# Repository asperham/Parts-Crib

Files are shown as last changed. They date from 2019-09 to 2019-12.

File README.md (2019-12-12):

# Parts-Crib/Luminosity Sensor Build Instructions

# Introduction 
This project utilizes the STM32, a V2 link, blue pill and the VCNL 4010 proximity sensor. The STM32 is an Arduino alternative that uses the Arduino IDE and has similar functions. For this project we will be using the I2C pins on the STM32 in order to get readings from the VCNL 4010. The V2 link simply allows us to use the STM32 with the Arduino IDE and the VCNL 4010 is a proximity and ambient sensor. The purpose of this project is to turn on another device when the user puts their phone close to the proximity sensor. To emulate this, we will simply use an LED on one of the output pins on the STM32 to ensure that we assembled it properly. 

The following is a schematic of the breadboard:
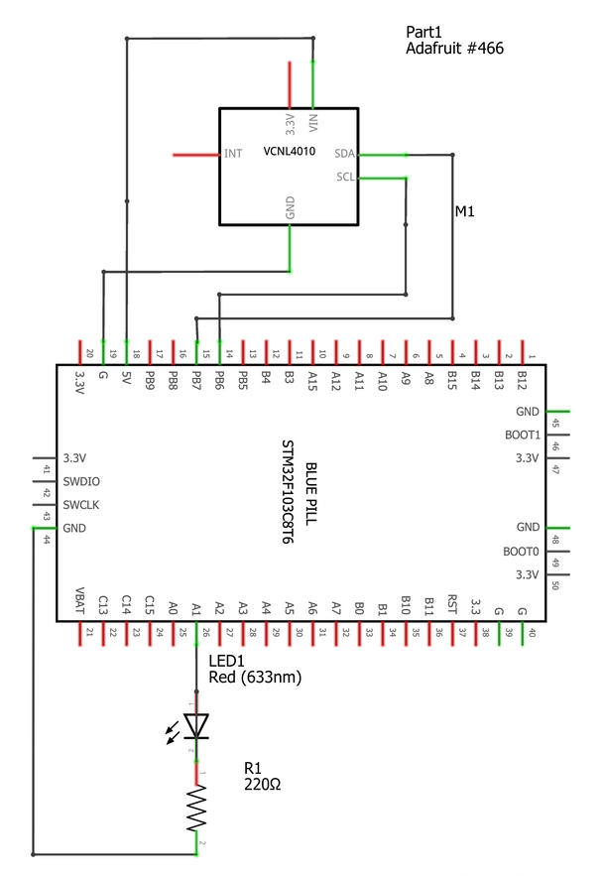
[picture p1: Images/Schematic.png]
Image of BreadBoard


The VCNL 4010 has a SCL and a SDA pins which we will connect to the I2C pin on the 4010 which are B6 and B7 respectively. The we can connect an LED to one of the output pins on the STM32 such as A1. The connections and setup will be covered on further detail in the Mechanocal Assembly section of this manuel.  

# Materials Required
The materials requred for this project are the STM32, a V2 link, the VCNL 4010, an LED, a resisor, PCB, M3 machine screws, and materials for 3D printing. You can refer to the following budget for materials: 

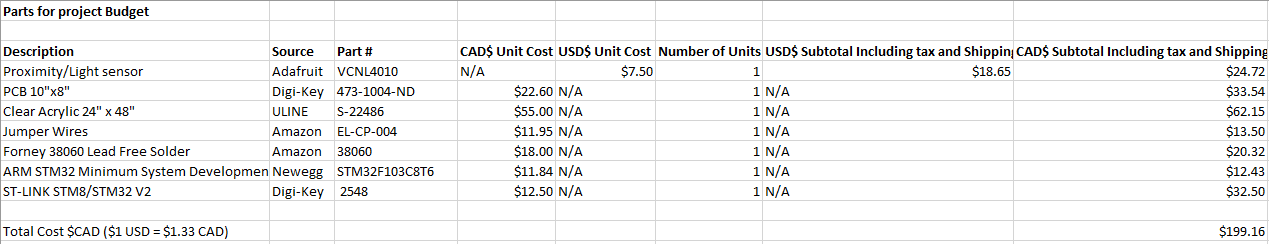
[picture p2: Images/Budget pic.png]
Image of Budget


# Time Commitment
This project can relaistically be compleated in a couple of weeks as it does not require a lot of waiting. The only things that will take the most time will be waiting for the parts, creating the PCB, and soldering. However, you can refer to the following time scedule: 

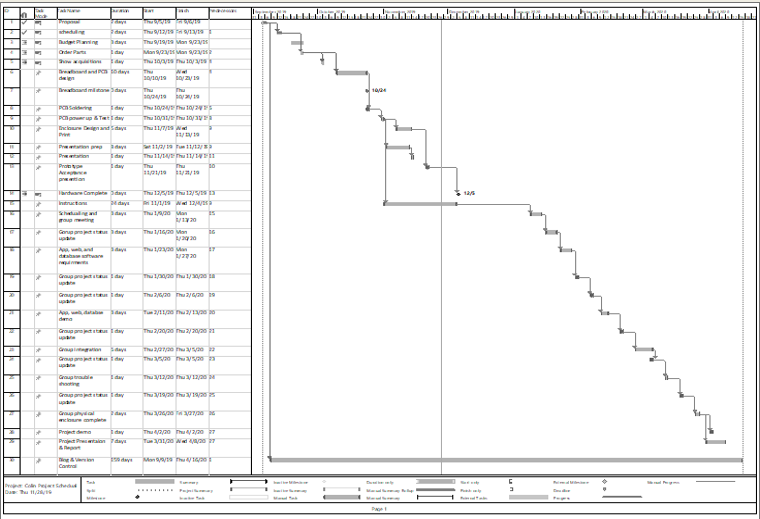
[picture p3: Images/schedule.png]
Image of schedule


# Mechanical Assembly
For the mechanical assembly we first need to test and create the breadboard. You can use the following design for the breadboard: 
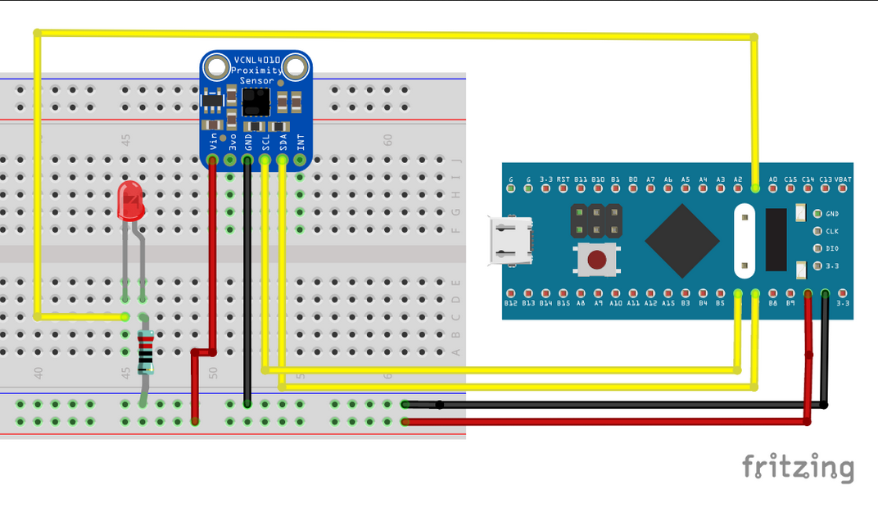
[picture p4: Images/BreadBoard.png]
Image of breadboard

Ensure that you have to proper pins connected. From here you can connect the V2 link into your computer by connecting the correspoding pins to the STM32. From here you can load the following code onto the STM32:

Link to code

From here you can you can put your hand infront of the VCNL4010 and the LED should turn on. If it does not, make sure that you initialize the I2C pins by importing the Wire.h header file and putting Wire.begin(); at the beginning of the code. 

From here we can now create the case for out PCB which will be made in the next step. The case will look like the following: 

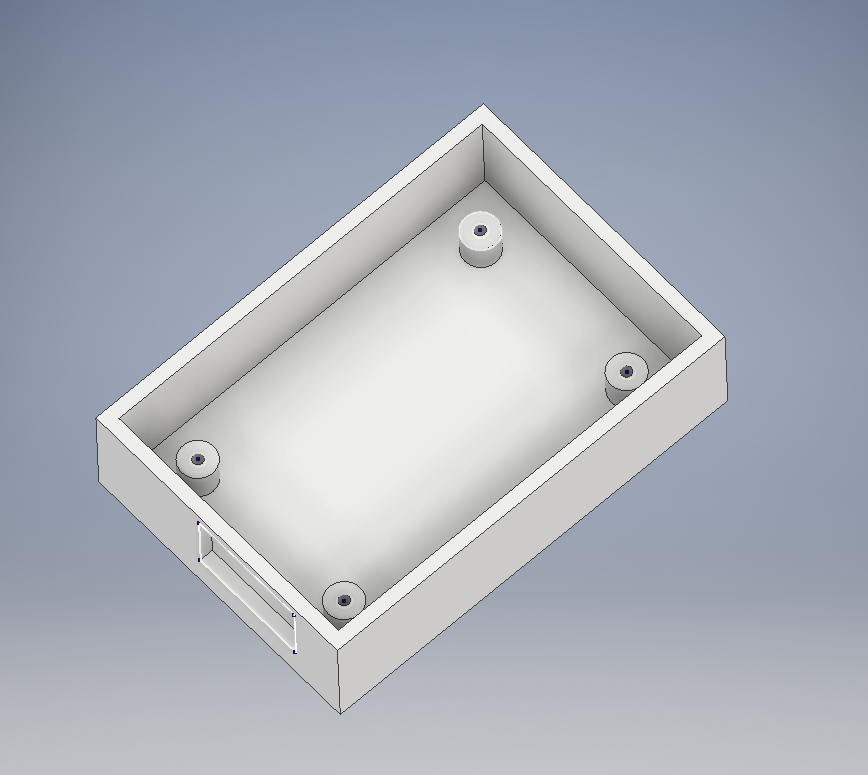
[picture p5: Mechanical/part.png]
image of case

The files for the case can be found here: Link to case files

The file is an STL file which needs to be sliced in software such as Cure before we can 3d print it. Once we slice it make sure that you add supports and fill the wall by about 50%. After this we can proceed to print the case. After it has completed and the breadboard works, we can move onto the next step.

# PCB / Soldering
For the PCB, we need to ensure that all pins are connected properly, For the PCB we can use headers, but they are not necessary for mass production. The PCB we will be creating will look like the following:
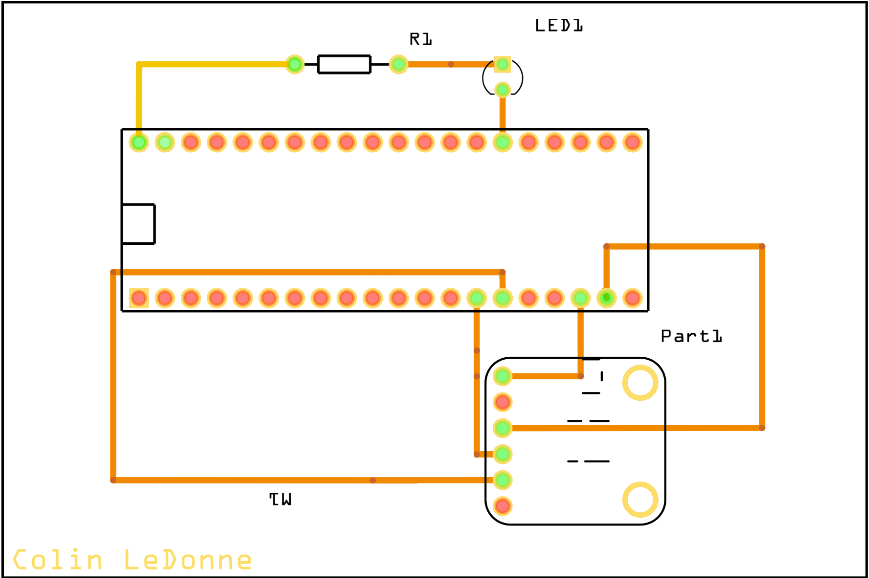
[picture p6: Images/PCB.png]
Image of PCB


For this to be created we need the gerber files which can be found From this link

Once we have the PCB created we can now solder the parts to the PCB. Ensure that you are properly safty trained before using a soldering iron. we are only going to solder the pins we need to be attached to the PCB however, you can still solder all of the pins to the PCB if you wish. Once compleated, the PCB should look somthing like the following:

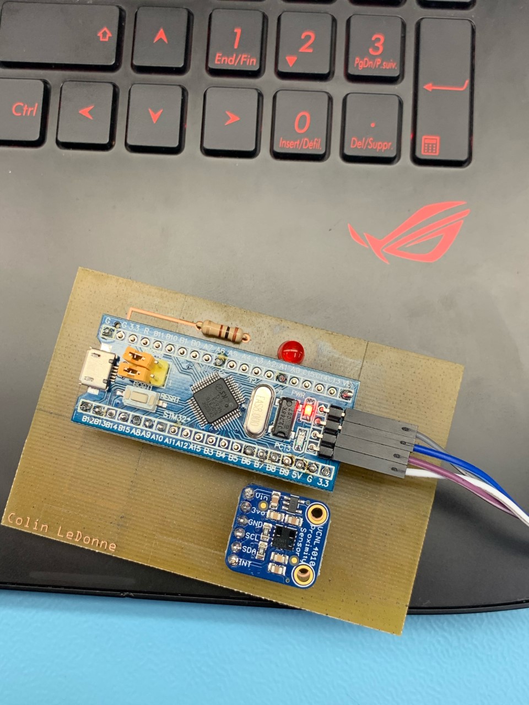
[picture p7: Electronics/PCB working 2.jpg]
image if PCB


Once all parts are soldered we can now trim the pins on the bottom of the PCB so we can put in into the case, but before we do this, we need to make sure that the PCB works properly.

# Power Up
Before you power up the PCB connect it to a multimeter with it connected to the power and ground. Ensure that you do not get any reading. If you get a reading, it means that you created a short. Check the soldering and make sure you did not create any uninteded connections. If you did, you can simply use a solder sucker to fix it. If you do not get a reading, we can now power it up. After poweing it up we can test that the PCB still works by putting out hand infront of the proximity sensor and it should look like the following: 

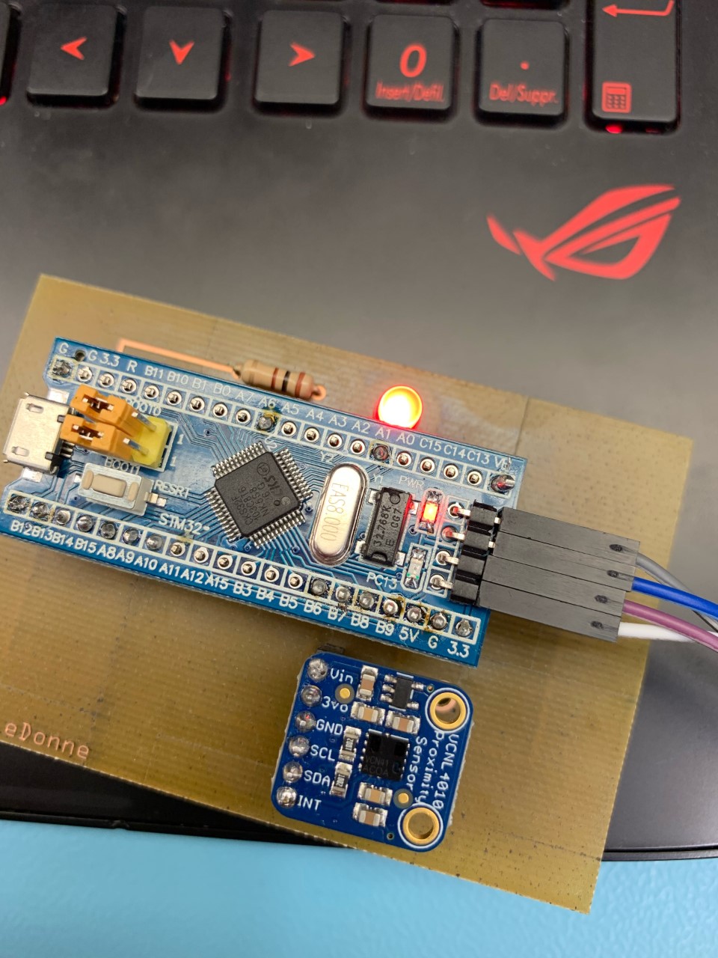
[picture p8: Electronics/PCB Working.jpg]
image of PCB on


From here we can now connect the PCB to the case we made earlier. To do this we need to make four holes on the corners of the PCB 7mm from each edge. Use a M3 machine screw drill bit since we will be using M3 machine screws to connect the PCB to the case. Once you made the holes, you can screw the PCB to the case and it should look like the following:

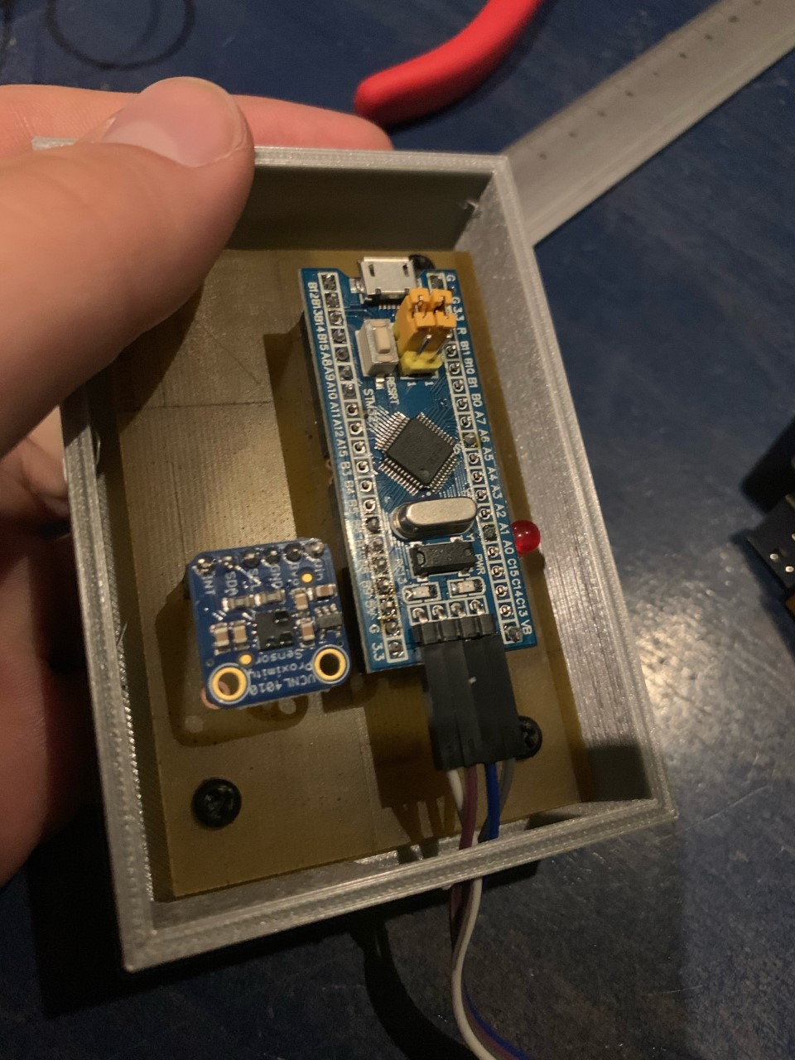
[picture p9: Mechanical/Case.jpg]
Image of Case


# Unit Testing
To test the unit, we can connect a micro USB to USB cable to the STM32 and connect it to a computer. On the computer, go to device manager to see what COM port the STM32 is connected to and take note. We can the use putty to connect to the serial output from the COM port of the STM32. From this, we can see actual values from the STM32. It should look like the following: 

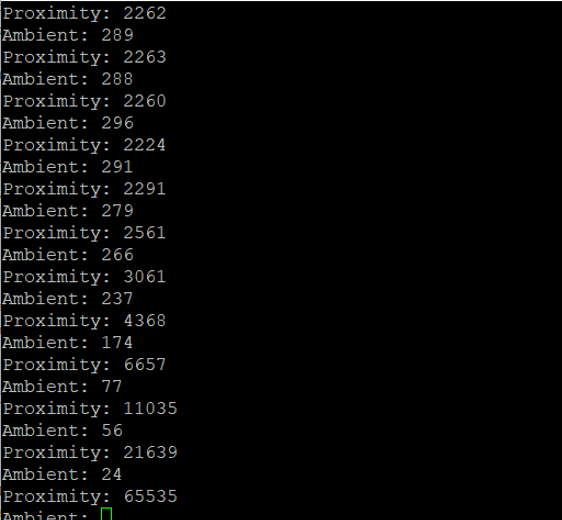
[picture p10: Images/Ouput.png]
image of output


The closer you get to the proximity sensor, the value of proximity gets higher and the value of ambient gets lower. These are unitless measurments so you are gunna have to play around with the tolerance you wish to use to turn on the LED. To do this, simply change the values of the if statment near the bottom of the code. 

# Production Testing
To test the viability of production for this unit, you can see what the total cost, and total time it takes to produce this product. For me, it took about 3 months working on it once a week with a total cost of about $50 since I had most of the required materials. Realistically, this project can be compleated in a couple of days if you work on some of the steps at the same time such as doing testing and printing the case and making the PCB at the same time. Also, once the code is finalized, you can just upload it to each new unit reducing the total time of the project. This whole unit is not to hard to replicate and it rather easy to construct.

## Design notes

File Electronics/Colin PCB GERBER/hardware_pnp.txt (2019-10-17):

*Pick And Place List
*Company=
*Author=
*eMail=
*
*Project=hardware
*Date=04:34:06
*CreatedBy=Fritzing 0.9.3b.04.19.5c895d327c44a3114e5fcc9d8260daf0cbb52806
*
*
*Coordinates in mm, always center of component
*Origin 0/0=Lower left corner of PCB
*Rotation in degree (0-360, math. pos.)
*
*No;Value;Package;X;Y;Rotation;Side;Name
1;;;68.0289;-27.4094;0;Bottom;BATT1
2;;;56.0909;-13.4394;90;Bottom;Part1
3;;1206 [SMD];47.4288;-50.2694;180;Top;LED1
4;;;37.4727;-35.0294;-90;Bottom;M1
5;220;2512 [SMD];38.5587;-50.2694;180;Top;R1

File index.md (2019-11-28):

(Week 12) Nov/28/19
-------
presentation has been compleated. [Link to pres](https://github.com/asperham/Parts-Crib/blob/master/Documentation/Sensor%20Pres.pptx)

Progress Report:

Everything is on scedule and no notable changes have been made to the budget. I got the output to work properly and I can see the output through putty. This makes it easier to code the distance tolerance to turn on LED. 

Image of Output

(Week 11) Nov/20/19
-------
Enclosure has been compleated and the following image is from autoCAD which is where the object was crated

Link to stl and dwg files 

[STL File](https://github.com/asperham/Parts-Crib/blob/master/Mechanical/CaseDrawing2.stl)

[DWG File](https://github.com/asperham/Parts-Crib/blob/master/Mechanical/CaseDrawing2.dwg)

Image of Case

Image of Drawing

Progress Report:

Everything is currently up to date and the case was printed and fits my PCB well. To make the 3D model, I used AutoDesk Inventor and AutoCAD. I first made the model in Inventor then expoted it to AutoCAD so I could then export it as a STL file. The only problem I had is that the PCB is mounted to the case woth 4 M3 6mm machine screws. In Inventor, I used the hole command to thred the inside of the cylinders that hold the PCB up and allows me to screw the PCB to the case. However, because of the ammount of time I can use at the 3d printer, I had to increase the layer size which didnt thred the holes properly. To fix this I used a treading drill bit and threded the holes myself. 
No notable changes have been made to the budget or plan. 

(Week 10) Nov/14/19
---------
PCB Powered up and is working. 
Following is the nothing infront of the 4010 Proximity Sensor: 
Image of PCB off
Following is when there is something (My Phone) infront of the proximity sensor: 
Image of PCB On

Progress Report: 

Everything is working as intended so far on the PCB. Today my professor noted how to use the serial monitor with the STM32 and I will try to get that working sometime this week. It will be useful to see the serial monitor as the code outputs the distance from the proximity sensor to the serial monitor. This means I can see the exact values for how far something is away form the sensor and I wont have to guess the number to put into the code. This will be especially useful when designing my case as I need to make sure that the sensor does not detect the case, but will detect something outside of the case (i.e a phone). I am currently working on a case for my PCB and should have it printed by next week. No notable changes have been made to the budget or overall project. As long as I get my case done by next week, everything will be on schedual according to the proposal. 

(Week 9) Nov/07/19
----------
PCB Soldering. The following is the complete soldering: 
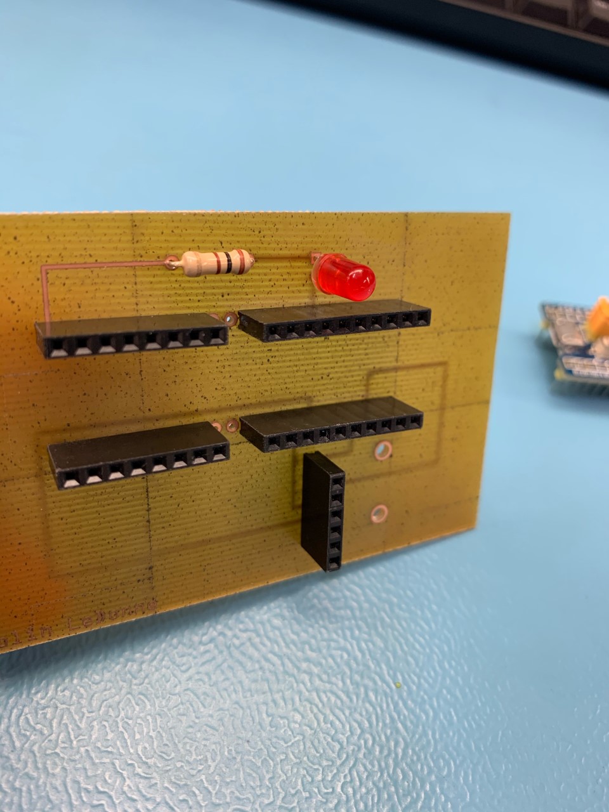
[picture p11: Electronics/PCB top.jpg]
Image of Top PCB

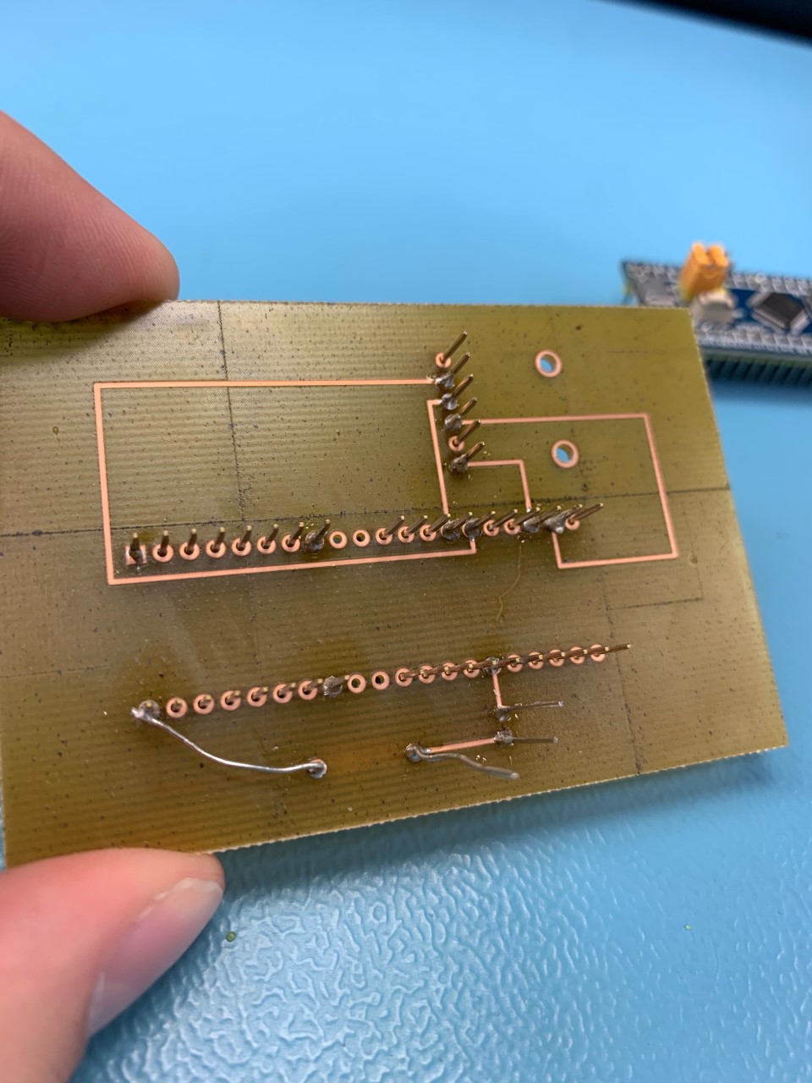
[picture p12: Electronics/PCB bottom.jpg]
Image if Bottom PCB


Progress Report: 
Everything on the PCB was fine expect the connection from the resistor to ground was printed on the top of the board instead of the bottom. To fix this, I simply soldered the wire from the resistor to the ground pin on the bottom of the board. This can be seen in the images from above. All connections are fine as there is no resistance from power to ground which means there are no shorts in the PCB. The project is on time and no notable changes have been made to the overall project. 

(Week 8) Oct/31/19
----------
Breadboard Milestone
Breadboard has been completed and is functioning. One thing to note is that there is no output screen since the STM32 does not have a serial console; so I can only show the breadboard working.
Link to the code for the STM32: [Link](https://github.com/asperham/Parts-Crib/blob/master/Software/hardware_project/hardware_project.ino)

The following pictures are the breadboard:
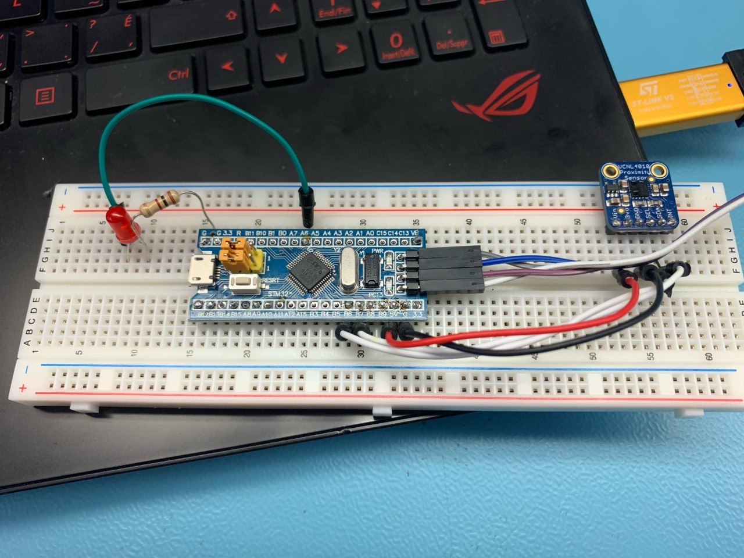
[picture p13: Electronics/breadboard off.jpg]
Image of breadboard Off

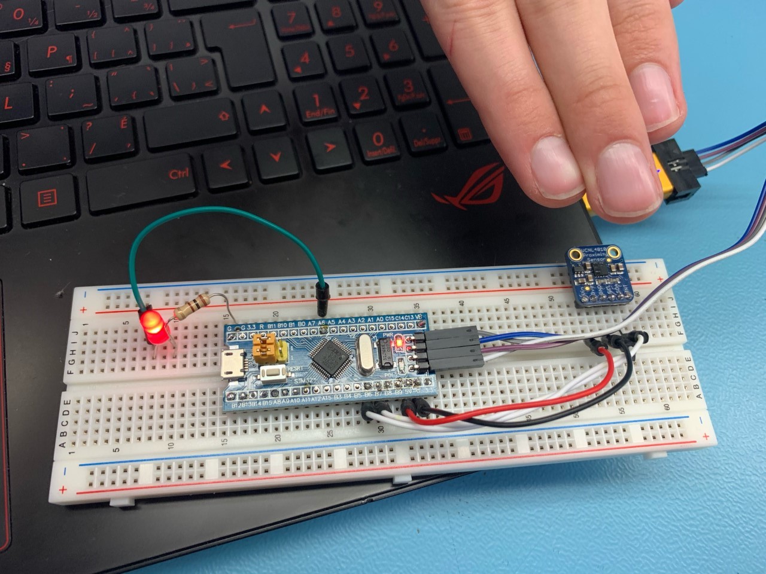
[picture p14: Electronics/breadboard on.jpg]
Image of breadboard On


Progress Report: 
Everything is going on track and I have gotten the STM32 bluepill and used it to complete my breadboard. I had some issues while getting my breadboard to work since the STM32 was not able to find the sensor. This was fixed by setting up the I2C pins on the STM32 and I had to fix some of my soldering. I had some help from my partner Rob in order to do this. The only notable change I made to the project is that I changed the PCB design. I realized that my older design would not have functioned as intended and now, after fixing it, the board should run as intended. Link to the updated PCB designs can be found here: [Link](https://github.com/asperham/Parts-Crib/tree/master/Electronics) 

(Week7) Oct/17/19
----------
Breadboard, PCB, and Schematics all have been made. [Link](https://github.com/asperham/Parts-Crib/tree/master/Electronics)

Progress Report: 
Everything is going on track, however I am still wating for my STM32 bluepill to come in the mail. It should arrive by Monday October the 21st. Once I get my bluepill, I will be able to test my connections to ensure my board will work properly. The only problem I currently face is that i'm not sure what the output pins are on the bluepill, but this should not be a problem once I can sit down and experiment to see what works. No changes have currently been made to the budget and everything is on schedule. I will work over the reading week to ensure I can meet the deadlines. 

(Week5) Oct/3/19
-----------
Parts have been ordered and the proof of purchase is as follows:

Sensor:

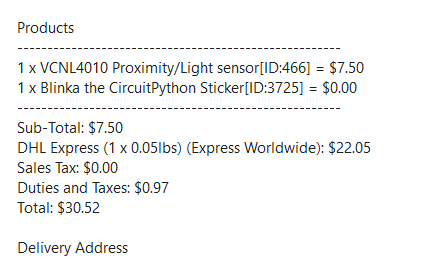
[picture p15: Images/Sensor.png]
Image of Sensor


V2 Link:

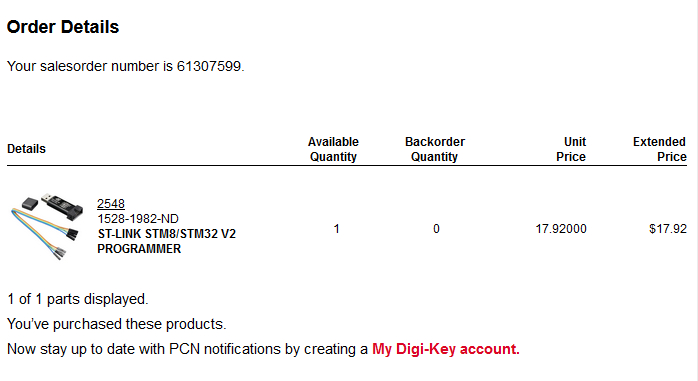
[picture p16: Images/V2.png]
Image of V2 link


BluePill:

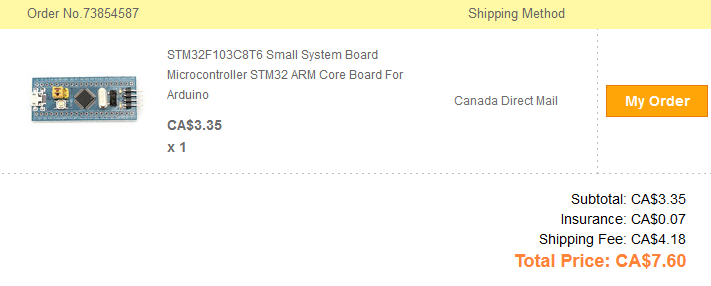
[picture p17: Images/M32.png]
Image of M32 breakout


(Week4) Sept/26/19
-----------
Budget Compleated [Link](https://github.com/asperham/Parts-Crib/blob/master/Documentation/Budget.xlsx)

(Week3) Sept/19/19
------------
Schedule Compleated [Link](https://github.com/asperham/Parts-Crib/blob/master/Documentation/Colin%20Project%20Schedual.mpp)

(Week 2) Sept/12/19:
-----------
Proposal Compleated. [Link](https://github.com/asperham/Parts-Crib/blob/master/Documentation/ProjectProposal%20Colin%20LeDonne%20Parts%20Crib.pdf)

(Week 1) Sept/05/19:
-----------
Repository Created!

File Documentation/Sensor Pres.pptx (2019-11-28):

## STM32 and VCNL 4010 sensor

Colin LeDonne

## Proposal

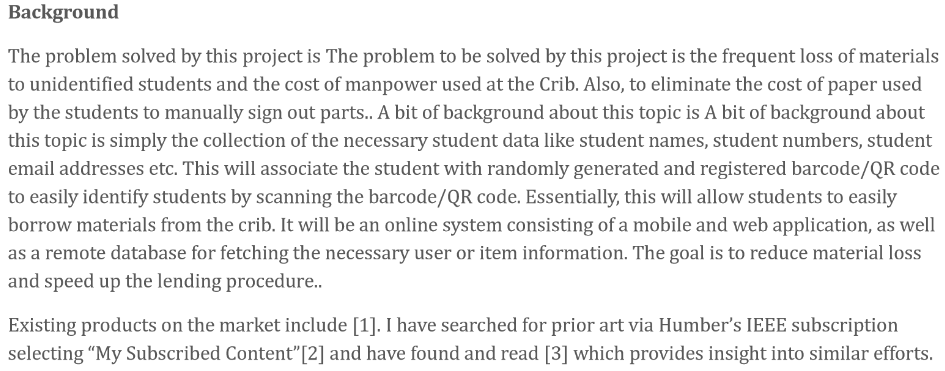
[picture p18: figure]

Link to full Proposal: https://github.com/asperham/Parts-Crib/blob/master/Documentation/ProjectProposal%20Colin%20LeDonne%20Parts%20Crib.pdf

## Budget

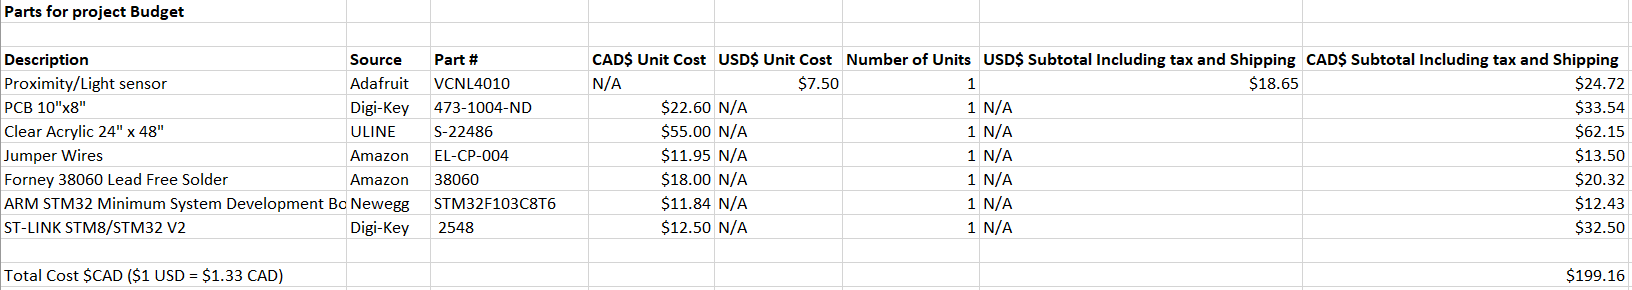
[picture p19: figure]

Link to budget: https://github.com/asperham/Parts-Crib/blob/master/Documentation/Budget.xlsx

## Schedule

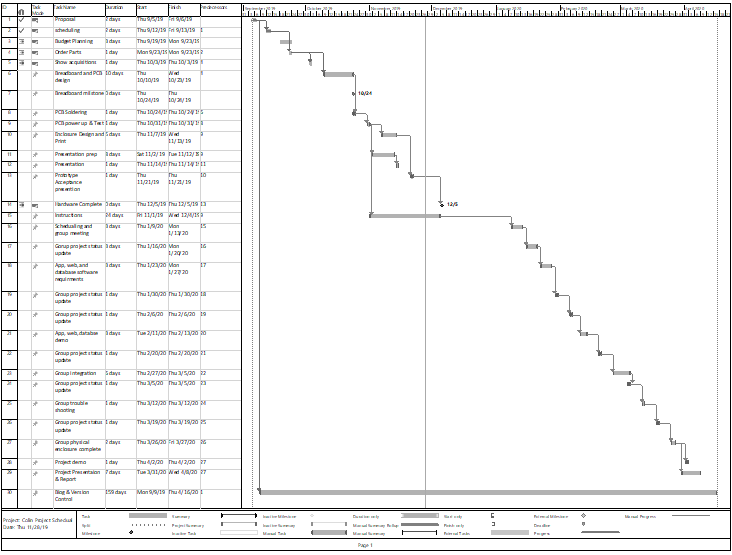
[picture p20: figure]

Link to Schedule: https://github.com/asperham/Parts-Crib/blob/master/Documentation/Colin%20Project%20Schedual.mpp

## PCB

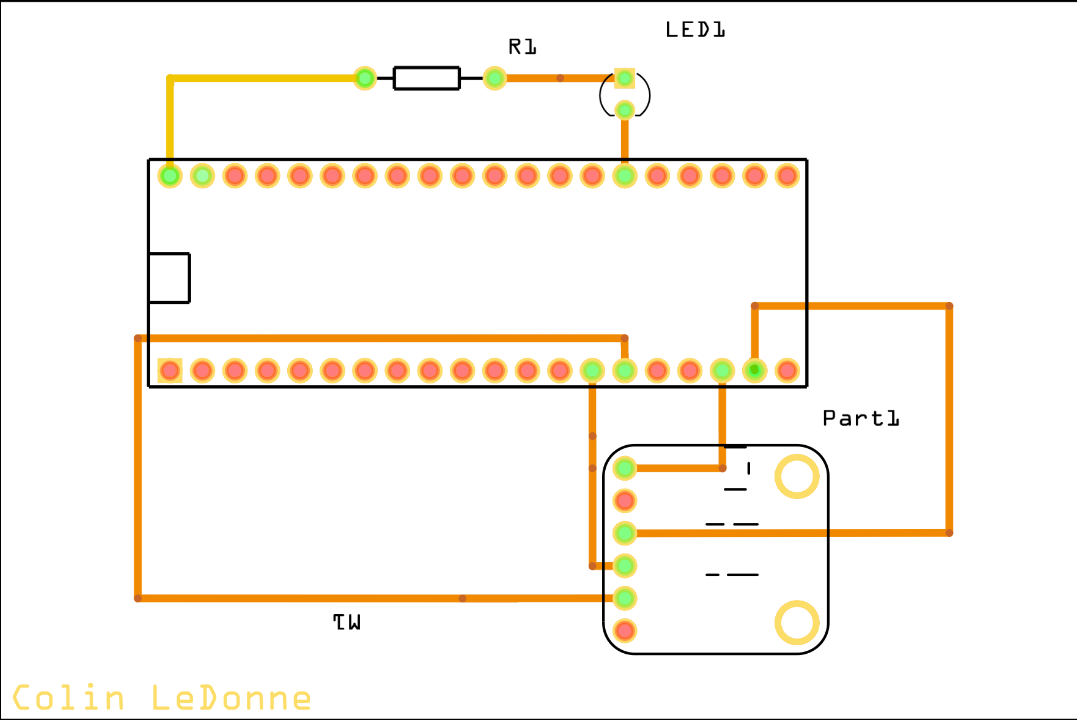
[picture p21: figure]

## Hardware

3D object file made in autoCAD


PCB in enclosure


## Readings

Uses I2C for I/O

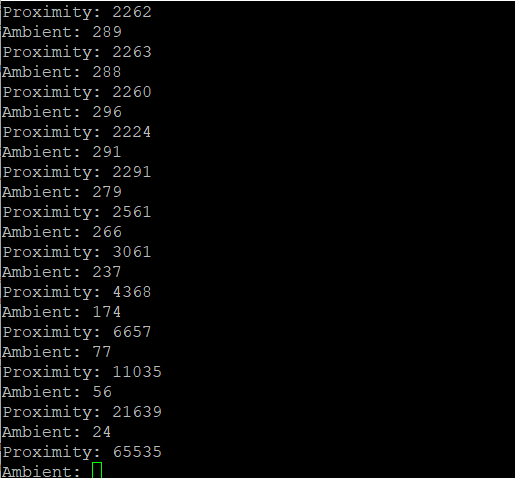
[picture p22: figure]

As object gets closer, Proximity gets higher and ambient gets lower

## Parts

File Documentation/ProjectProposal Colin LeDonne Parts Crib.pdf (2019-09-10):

43720

Proposal for the development of Parts Crib Sign In/Out Solutuon

Prepared by Colin LeDonne, Robert Dinh, Jonathan Luong Computer Engineering Technology Students https://asperham.github.io/Parts-Crib/

Executive Summary

As a student in the Computer Engineering Technology program, I will be integrating the knowledge and skills I have learned from our program into this Internet of Things themed capstone project. This proposal requests the approval to build the hardware portion that will connect to a database as well as to a mobile device application. The internet connected hardware will include a custom PCB with the following sensors and actuators Sensors: NFC/RFID, LCD Display, Luminosity. I will be doing the Luminosity Sensor.. The database will store The database will store the Students ID, studens email, student name, Parts Signed out, The Date and time of signout, date and time signin. And total parts avilable.. The mobile device functionality will include The modile device will allow the user to queue items before they arrive at the crib. This will then create a QR code or NFC tag that the user can scan at the Crib to borrow the parts they need. The app will also have a searh fuction that will allow the user to find parts more easily and will need WI-FI access so the app can check the database to insure that the parts are available to sign out. The hardware will allow students to scan their code which will then add an entry to the database and allow students to sign out matterials. My sensor, the luminosity sensor, will be used to power the NFC reader when the user hovers their phone over the unit. This is so the reader is not always running saving on power consumption. and will be further detailed in the mobile application proposal. I will be collaborating with the following company/department We will be collaborating with the parts Crib at Humber north and the Company contact is Kristian Medri.. In the winter semester I plan to form a group with the following students, who are also building similar hardware this term and working on the mobile application with me The group in the Winter semestar will remain the same including: Colin LeDonne, Robert Dinh, Jonathan Luong. The hardware will be completed in CENG 317 Hardware Production Techniques independently and the application will be completed in CENG 319 Software Project. These will be integrated together in the subsequent term in CENG 355 Computer Systems Project as a member of a 2 or 3 student group.

Background

The problem solved by this project is The problem to be solved by this project is the frequent loss of materials to unidentified students and the cost of manpower used at the Crib. Also, to eliminate the cost of paper used by the students to manually sign out parts.. A bit of background about this topic is A bit of background about this topic is simply the collection of the necessary student data like student names, student numbers, student email addresses etc. This will associate the student with randomly generated and registered barcode/QR code to easily identify students by scanning the barcode/QR code. Essentially, this will allow students to easily borrow materials from the crib. It will be an online system consisting of a mobile and web application, as well as a remote database for fetching the necessary user or item information. The goal is to reduce material loss and speed up the lending procedure..

Existing products on the market include [1]. I have searched for prior art via Humber’s IEEE subscription selecting “My Subscribed Content”[2] and have found and read [3] which provides insight into similar efforts.

In the Computer Engineering Technology program we have learned about the following topics from the respective relevant courses:

- Java Docs from CENG 212 Programming Techniques In Java,
- Construction of circuits from CENG 215 Digital And Interfacing Systems,
- Rapid application development and Gantt charts from CENG 216 Intro to Software Engineering,
- Micro computing from CENG 252 Embedded Systems,
- SQL from CENG 254 Database With Java,
- Web access of databases from CENG 256 Internet Scripting; and,
- Wireless protocols such as 802.11 from TECH152 Telecom Networks.

This knowledge and skill set will enable me to build the subsystems and integrate them together as my capstone project.

Methodology

This proposal is assigned in the first week of class and is due at the beginning of class in the second week of the fall semester. My coursework will focus on the first two of the 3 phases of this project:
Phase 1 Hardware build.
Phase 2 System integration.
Phase 3 Demonstration to future employers.

Phase 1 Hardware build

The hardware build will be completed in the fall term. It will fit within the CENG Project maximum dimensions of 12 13/16" x 6" x 2 7/8" (32.5cm x 15.25cm x 7.25cm) which represents the space below the tray in the parts kit. The highest AC voltage that will be used is 16Vrms from a wall adaptor from which +/-15V or as high as 45 VDC can be obtained. Maximum power consumption will be 20 Watts.

Phase 2 System integration

The system integration will be completed in the fall term.

Phase 3 Demonstration to future employers

This project will showcase the knowledge and skills that I have learned to potential employers.

The brief description below provides rough effort and non-labour estimates respectively for each phase. A Gantt chart will be added by week 3 to provide more project schedule details and a more complete budget will be added by week 4. It is important to start tasks as soon as possible to be able to meet deadlines.
Raspberry PI 3 B+ ($85.00) and a luminosity sensor (~$10.00). In total approximatly $90-$100

Concluding remarks

This proposal presents a plan for providing an IoT solution for The solution to this problem is to reduce the loss of parts from the parts crib. Utizling an system that better keeps track of studnts can help in reducing the loss of parts. This is accomplished by requiring the students to create an account with the application which will add their information to a database. Thus, if they do not return the materils they borrowed within 24 hours, they will be sent a email telling them to return it. If the student still does not return the materials they will be emailed a bill.. This is an opportunity to integrate the knowledge and skills developed in our program to create a collaborative IoT capstone project demonstrating my ability to learn how to support projects such as the initiative described by [3]. I request approval of this project.

References

[1] ada, lady. (n.d.). Adafruit TSL2591 High Dynamic Range Digital LightSensor. Retrieved from https://cdn-learn.adafruit.com/downloads/pdf/adafruit-tsl2591.pdf
[2] Institute of Electrical and Electronics Engineers. (2015, August 28). IEEE Xplore Digital Library [Online]. Available: https://ieeexplore.ieee.org/search/advsearch.jsp
[3] Cho, B. R., Koh, S., Park, J.-K., Kim, C.-H., & Lee, S. (2019). Fundamental Experiment on Relationship Between External Force and Light Intensity in Soft Tactile Sensor Using Sponge. 2019 International Conference on Systems, Signals and Image Processing (IWSSIP). doi: 10.1109/iwssip.2019.8787264

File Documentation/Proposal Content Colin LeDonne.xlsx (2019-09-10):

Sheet: DataEntry
Submission Date | 2019-09-12
Project Name | Parts Crib Sign In/Out Solutuon
Student Names | Colin LeDonne, Robert Dinh, Jonathan Luong
Project repository | https://asperham.github.io/Parts-Crib/
SensorsEffectors choices | Sensors: NFC/RFID, LCD Display, Luminosity. I will be doing the Luminosity Sensor.
The database will store | The database will store the Students ID, studens email, student name, Parts Signed out, The Date and time of signout, date and time signin. And total parts avilable.
The mobile device functionality will include | The modile device will allow the user to queue items before they arrive at the crib. This will then create a QR code or NFC tag that the user can scan at the Crib to borrow the parts they need. The app will also have a searh fuction that will allow the user to find parts more easily and will need WI-FI access so the app can check the database to insure that the parts are available to sign out. The hardware will allow students to scan their code which will then add an entry to the database and allow students to sign out matterials. My sensor, the luminosity sensor, will be used to power the NFC reader when the user hovers their phone over the unit. This is so the reader is not always running saving on power consumption.
I will be collaborating with the following company/department | We will be collaborating with the parts Crib at Humber north and the Company contact is Kristian Medri.
My group in the winter semester will include | The group in the Winter semestar will remain the same including: Colin LeDonne, Robert Dinh, Jonathan Luong
50 word problem statement | The problem to be solved by this project is the frequent loss of materials to unidentified students and the cost of manpower used at the Crib. Also, to eliminate the cost of paper used by the students to manually sign out parts.
100 words of background | A bit of background about this topic is simply the collection of the necessary student data like student names, student numbers, student email addresses etc. This will associate the student with randomly generated and registered barcode/QR code to easily identify students by scanning the barcode/QR code. Essentially, this will allow students to easily borrow materials from the crib. It will be an online system consisting of a mobile and web application, as well as a remote database for fetching the necessary user or item information. The goal is to reduce material loss and speed up the lending procedure.
Current product APA citation | ada, lady. (n.d.). Adafruit TSL2591 High Dynamic Range Digital LightSensor. Retrieved from https://cdn-learn.adafruit.com/downloads/pdf/adafruit-tsl2591.pdf
Existing research IEEE paper APA citation | Cho, B. R., Koh, S., Park, J.-K., Kim, C.-H., & Lee, S. (2019). Fundamental Experiment on Relationship Between External Force and Light Intensity in Soft Tactile Sensor Using Sponge. 2019 International Conference on Systems, Signals and Image Processing (IWSSIP). doi: 10.1109/iwssip.2019.8787264
Brief description of planned purchases | Raspberry PI 3 B+ ($85.00) and a luminosity sensor (~$10.00). In total approximatly $90-$100
Solution description | The solution to this problem is to reduce the loss of parts from the parts crib. Utizling an system that better keeps track of studnts can help in reducing the loss of parts. This is accomplished by requiring the students to create an account with the application which will add their information to a database. Thus, if they do not return the materils they borrowed within 24 hours, they will be sent a email telling them to return it. If the student still does not return the materials they will be emailed a bill.

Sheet: DataBase
Submission Date | Project Name | Student Names | Project repository | SensorsEffectors choices | The database will store | The mobile device functionality will include | I will be collaborating with the following company/department | My group in the winter semester will include | 50 word problem statement | 100 words of background | Current product APA citation | Existing research IEEE paper APA citation | Brief description of planned purchases | Solution description
43720 | Parts Crib Sign In/Out Solutuon | Colin LeDonne, Robert Dinh, Jonathan Luong | https://asperham.github.io/Parts-Crib/ | Sensors: NFC/RFID, LCD Display, Luminosity. I will be doing the Luminosity Sensor. | The database will store the Students ID, studens email, student name, Parts Signed out, The Date and time of signout, date and time signin. And total parts avilable. | The modile device will allow the user to queue items before they arrive at the crib. This will then create a QR code or NFC tag that the user can scan at the Crib to borrow the parts they need. The app will also have a searh fuction that will allow the user to find parts more easily and will need WI-FI access so the app can check the database to insure that the parts are available to sign out. The hardware will allow students to scan their code which will then add an entry to the database and allow students to sign out matterials. My sensor, the luminosity sensor, will be used to power the NFC reader when the user hovers their phone over the unit. This is so the reader is not always running saving on power consumption. | We will be collaborating with the parts Crib at Humber north and the Company contact is Kristian Medri. | The group in the Winter semestar will remain the same including: Colin LeDonne, Robert Dinh, Jonathan Luong | The problem to be solved by this project is the frequent loss of materials to unidentified students and the cost of manpower used at the Crib. Also, to eliminate the cost of paper used by the students to manually sign out parts. | A bit of background about this topic is simply the collection of the necessary student data like student names, student numbers, student email addresses etc. This will associate the student with randomly generated and registered barcode/QR code to easily identify students by scanning the barcode/QR code. Essentially, this will allow students to easily borrow materials from the crib. It will be an online system consisting of a mobile and web application, as well as a remote database for fetching the necessary user or item information. The goal is to reduce material loss and speed up the lending procedure. | ada, lady. (n.d.). Adafruit TSL2591 High Dynamic Range Digital LightSensor. Retrieved from https://cdn-learn.adafruit.com/downloads/pdf/adafruit-tsl2591.pdf | Cho, B. R., Koh, S., Park, J.-K., Kim, C.-H., & Lee, S. (2019). Fundamental Experiment on Relationship Between External Force and Light Intensity in Soft Tactile Sensor Using Sponge. 2019 International Conference on Systems, Signals and Image Processing (IWSSIP). doi: 10.1109/iwssip.2019.8787264 | Raspberry PI 3 B+ ($85.00) and a luminosity sensor (~$10.00). In total approximatly $90-$100 | The solution to this problem is to reduce the loss of parts from the parts crib. Utizling an system that better keeps track of studnts can help in reducing the loss of parts. This is accomplished by requiring the students to create an account with the application which will add their information to a database. Thus, if they do not return the materils they borrowed within 24 hours, they will be sent a email telling them to return it. If the student still does not return the materials they will be emailed a bill.

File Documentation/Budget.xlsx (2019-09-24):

Parts for project Budget
Description | Source | Part # | CAD$ Unit Cost | USD$ Unit Cost | Number of Units | USD$ Subtotal Including tax and Shipping | CAD$ Subtotal Including tax and Shipping | Link
Proximity/Light sensor | Adafruit | VCNL4010 | N/A | $7.50 | 1 | $18.65 | $24.72 | https://www.adafruit.com/product/466?gclid=COuS876n88sCFc5hfgodfY4Jbg
PCB 10"x8" | Digi-Key | 473-1004-ND | $22.60 | N/A | 1 | N/A | $33.54 | https://www.digikey.ca/product-detail/en/mg-chemicals/515/473-1004-ND/559722?productid=559722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
Clear Acrylic 24" x 48" | ULINE | S-22486 | $55.00 | N/A | 1 | N/A | $62.15 | https://www.uline.ca/BL_2386/Plexiglas-Sheets?keywords=acrylic
Jumper Wires | Amazon | EL-CP-004 | $11.95 | N/A | 1 | N/A | $13.50 | https://www.amazon.ca/Elegoo-120pcs-Multicolored-Breadboard-arduino/dp/B01EV70C78?hvadid=292982668700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
Forney 38060 Lead Free Solder | Amazon | 38060 | $18.00 | N/A | 1 | N/A | $20.32 | https://www.amazon.ca/Forney-38061-Solder-Antimony-2-Pound/dp/B003X3UA24?hvadid=231052748344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
ARM STM32 Minimum System Development Board | Newegg | STM32F103C8T6 | $11.84 | N/A | 1 | N/A | $12.43 | https://www.newegg.ca/p/2S7-01JA-0SVC3?item=9SIAJ4598E6200&nm_mc=knc-googleadwordscamkpl-pc
ST-LINK STM8/STM32 V2 | Digi-Key | 2548 | $12.50 | N/A | 1 | N/A | $32.50 | https://www.digikey.ca/product-detail/en/adafruit-industries-llc/2548/1528-1982-ND/6827110?productid=6827110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
Total Cost $CAD ($1 USD = $1.33 CAD) |  |  |  |  |  |  | $199.16

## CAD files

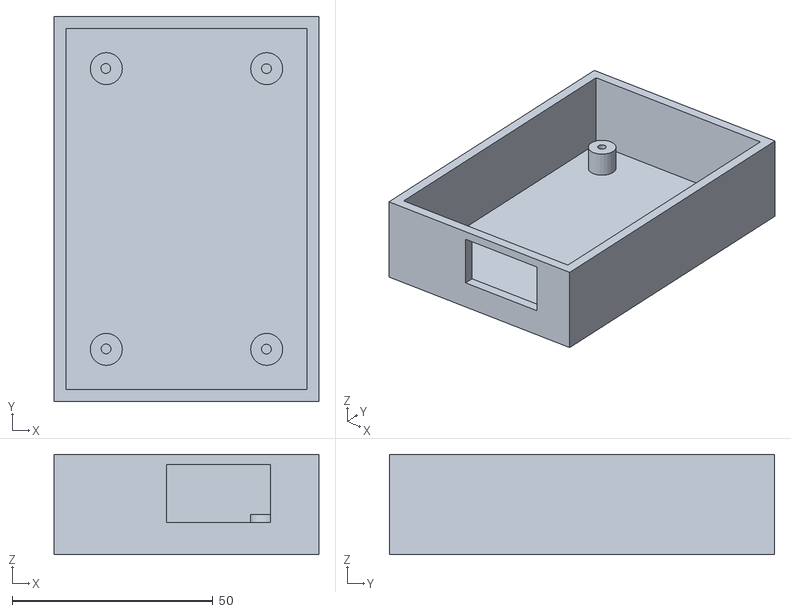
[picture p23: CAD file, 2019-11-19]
Mechanical/CaseDrawing2.stl
66.0 x 96.0 x 25.0

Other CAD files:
Mechanical/CaseDrawing2.dwg
Mechanical/CaseDrawing2.ipt

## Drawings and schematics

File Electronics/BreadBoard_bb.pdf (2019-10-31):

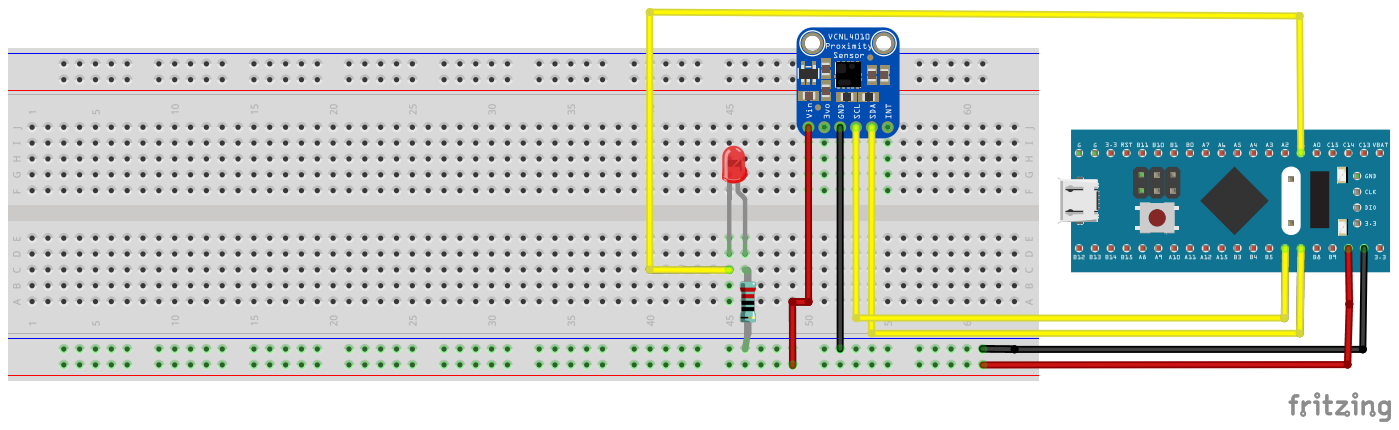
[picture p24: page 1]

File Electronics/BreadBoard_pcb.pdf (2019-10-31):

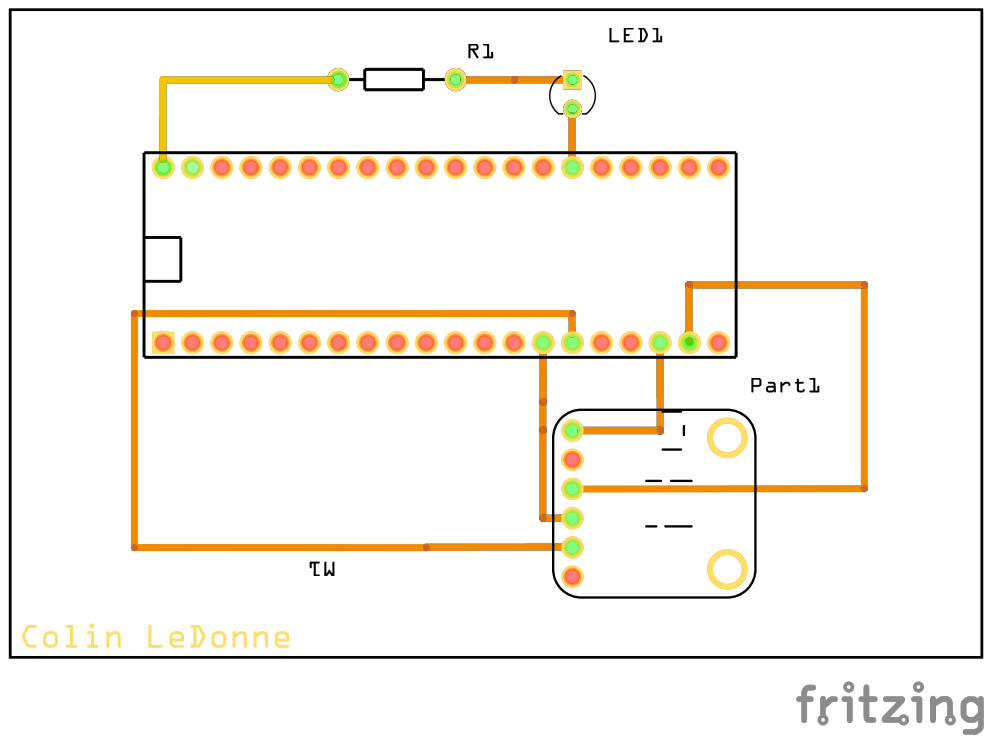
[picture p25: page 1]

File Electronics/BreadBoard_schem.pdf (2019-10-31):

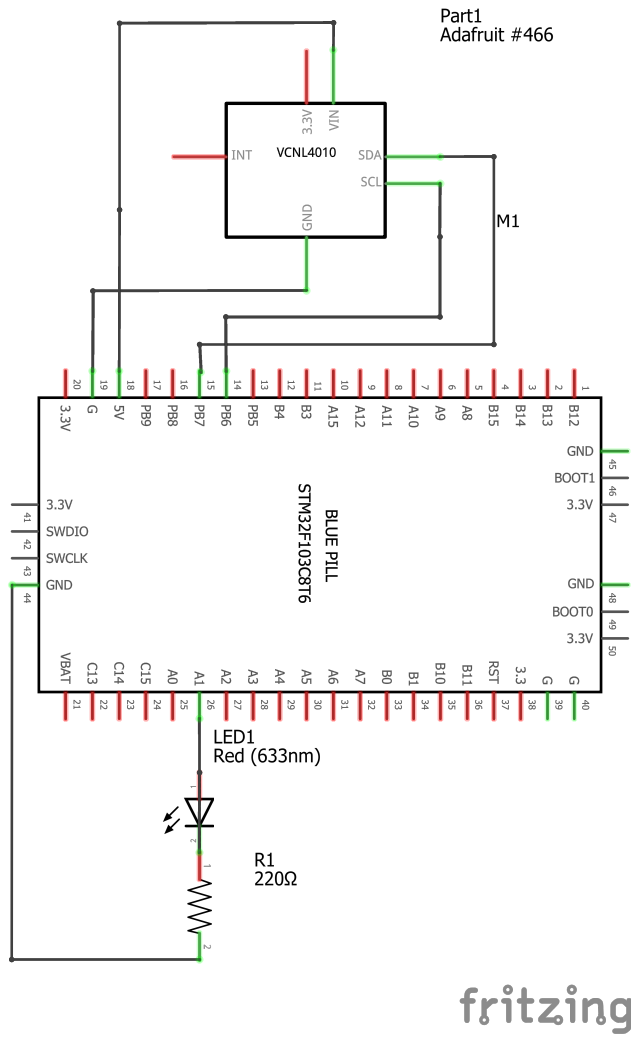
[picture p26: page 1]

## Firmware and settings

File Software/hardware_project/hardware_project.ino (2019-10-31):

#include <Wire.h>
#include<SoftWire.h> 
#include "Adafruit_VCNL4010.h"

Adafruit_VCNL4010 vcnl;

void setup() {
  Serial.begin(9600); //i2c address 13
  Serial.println("VCNL4010 test");
  pinMode(PA6, OUTPUT);
  Wire.begin(); 
  digitalWrite(PA6, LOW);
 
  if (! vcnl.begin()){
    Serial.println("Sensor not found :(");
    while (1);
  }
  Serial.println("Found VCNL4010");
}

void loop() {
  if(vcnl.readProximity() >= 2250){ 
    digitalWrite(PA6, HIGH);
  }
  else{
    digitalWrite(PA6, LOW);
  }
   Serial.print("Ambient: "); Serial.println(vcnl.readAmbient());
   Serial.print("Proximity: "); Serial.println(vcnl.readProximity());
   delay(100);
}

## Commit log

2019-09-10 Added folders and documentation
    [Proposal Content Colin LeDonne.xlsx]
2019-09-24 Create Budget.xlsx
    Budget uploaded
    [Budget.xlsx]
2019-10-17 Added Fritzing
    [hardware.fzz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]
2019-10-31 Updating breadboard
    [hardware.fzz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]
2019-11-07 adding PCB
2019-11-19 Added mechanical
    [CaseDrawing2.dwg, CaseDrawing2.ipt, CaseDrawing2.stl]
2019-11-28 Create Sensor Pres.pptx
